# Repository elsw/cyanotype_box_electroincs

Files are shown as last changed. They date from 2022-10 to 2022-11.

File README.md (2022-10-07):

# cyanotype_box_electronics

This is project for use with creating cyanotypes using high power UV LEDs.

These PCBS are designed to control the exposure time and intensity using a LCB screen and keypad

## PCBs

The PCBs are split into 2 parts, control box and light board.

Once control box can support up to 10 light boards daisy chained together

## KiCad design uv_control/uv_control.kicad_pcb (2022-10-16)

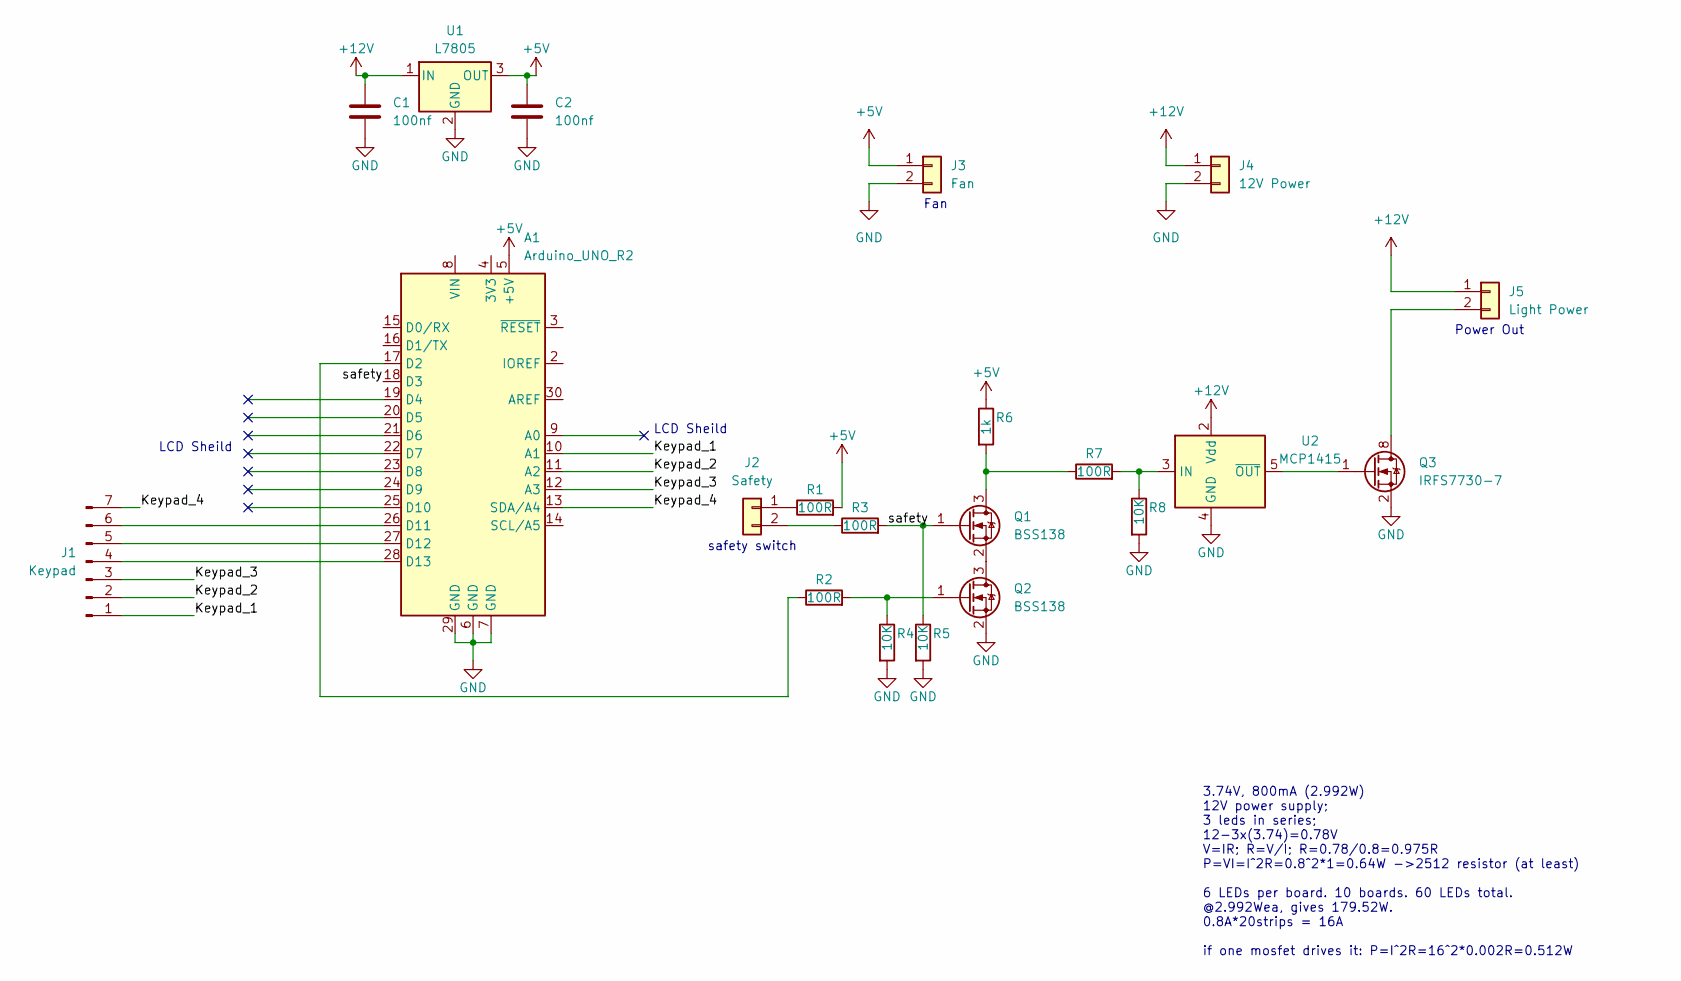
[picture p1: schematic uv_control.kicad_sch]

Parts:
A1: Arduino_UNO_R2
C1, C2: 100nf; C_1206_3216Metric
J1: Keypad; JST_EH_B7B-EH-A_1x07_P2.50mm_Vertical
J2: Safety; JST_EH_B2B-EH-A_1x02_P2.50mm_Vertical
J3: Fan; JST_EH_B2B-EH-A_1x02_P2.50mm_Vertical
J4: 12V Power; AMASS_XT60-M_1x02_P7.20mm_Vertical
J5: Light Power; AMASS_XT60-F_1x02_P7.20mm_Vertical
Q1, Q2: BSS138; SOT-23
Q3: IRFS7730-7; TO-263-7_TabPin8
R1, R2, R3, R7: 100R; R_0805_2012Metric
R4, R5, R8: 10K; R_0805_2012Metric
R6: 1k; R_0805_2012Metric
U1: L7805; TO-252-2
U2: MCP1415; SOT-23-5

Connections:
+5V: A1.5 (+5V), C2.1, J3.1, R1.2, R6.1, U1.3 (OUT)
+12V: C1.1, J4.1, J5.1, U1.1 (IN), U2.2 (Vdd)
/Keypad_1: A1.10 (A1), J1.1
/Keypad_2: A1.11 (A2), J1.2
/Keypad_3: A1.12 (A3), J1.3
/safety: A1.18 (D3), Q1.1 (G), R3.2, R5.1
GND: A1.6 (GND), A1.7 (GND), A1.29 (GND), C1.2, C2.2, J3.2, J4.2, Q2.2 (S), Q3.2 (S), Q3.3 (S), Q3.4 (S), Q3.5 (S), Q3.6 (S), Q3.7 (S), R4.2, R5.2, R8.2, U1.2 (GND), U2.4 (GND)
unnamed: A1.13 (SDA/A4), A1.16 (D1/TX), J1.7
unnamed: A1.17 (D2), R2.1
unnamed: A1.26 (D11), J1.6
unnamed: A1.27 (D12), J1.5
unnamed: A1.28 (D13), J1.4
unnamed: J2.1, R1.1
unnamed: J2.2, R3.1
unnamed: J5.2, Q3.8 (D)
unnamed: Q1.2 (S), Q2.3 (D)
unnamed: Q1.3 (D), R6.2, R7.1
unnamed: Q2.1 (G), R2.2, R4.1
unnamed: Q3.1 (G), U2.5 (~OUT)
unnamed: R7.2, R8.1, U2.3 (IN)

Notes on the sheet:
LCD Sheild
3.74V, 800mA (2.992W) 12V power supply; 3 leds in series; 12-3x(3.74)=0.78V V=IR; R=V/I; R=0.78/0.8=0.975R P=VI=I^2R=0.8^2*1=0.64W ->2512 resistor (at least) 6 LEDs per board. 10 boards. 60 LEDs total. @2.992Wea, gives 179.52W. 0.8A*20strips = 16A if one mosfet drives it: P=I^2R=16^2*0.002R=0.512W
Power Out
Fan
safety switch

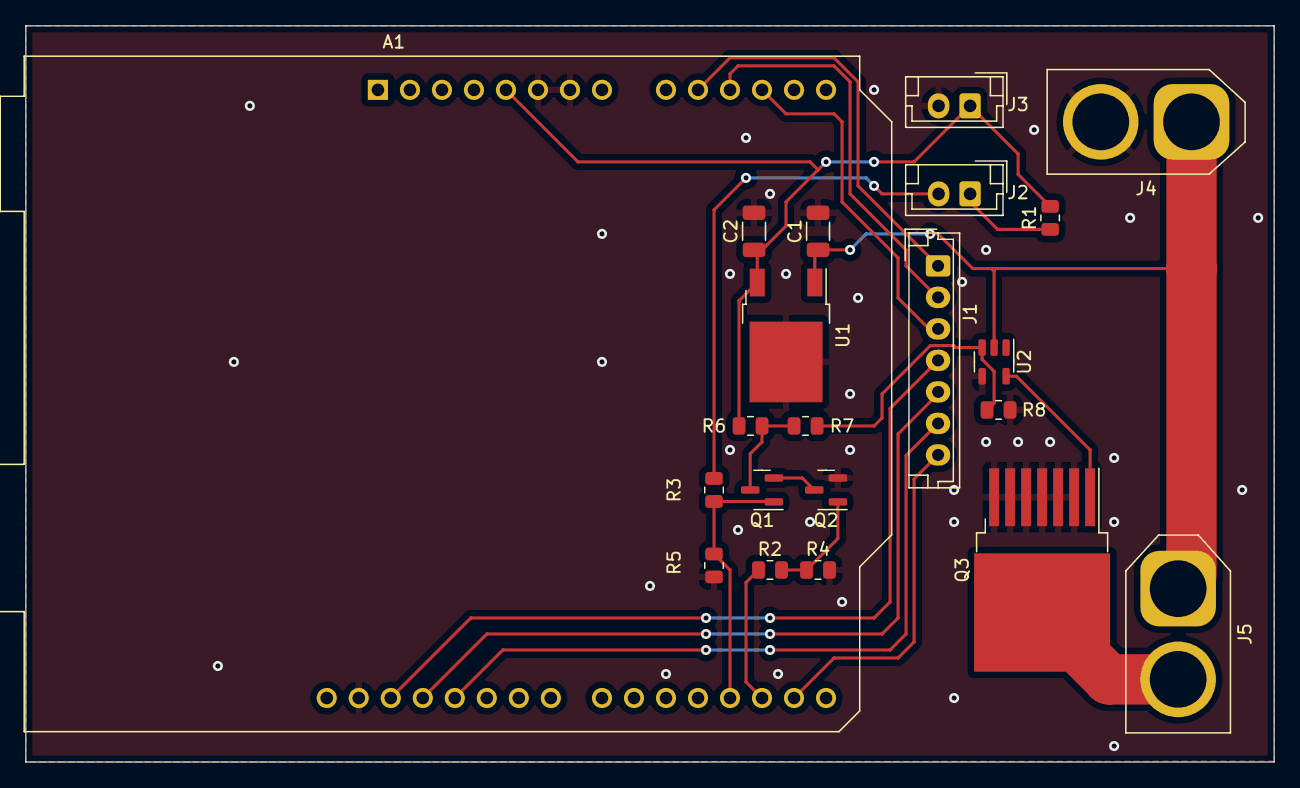
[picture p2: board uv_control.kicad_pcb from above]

Board: 2 copper layers, 99.1 x 58.4 mm, 21 parts (0 on the bottom side), 20 nets.

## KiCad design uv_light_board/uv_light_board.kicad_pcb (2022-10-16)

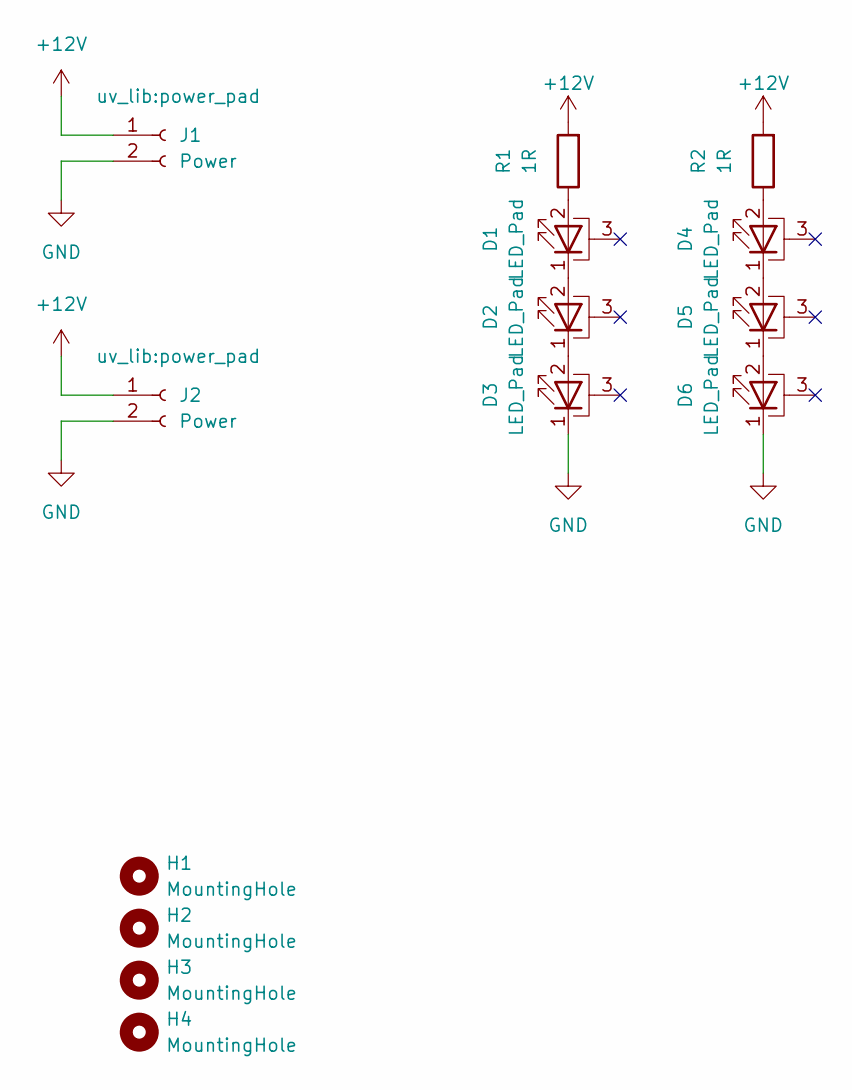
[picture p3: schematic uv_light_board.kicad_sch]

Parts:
D1, D2, D3, D4, D5, D6: LED_Pad; LED_1W_3W_R8
H1, H2, H3, H4: MountingHole; MountingHole_3.2mm_M3
J1, J2: Power; power_pad
R1, R2: 1R; R_2512_6332Metric

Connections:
+12V: J1.1, J2.1, R1.2, R2.2
GND: D3.1 (K), D6.1 (K), J1.2, J2.2
unnamed: D1.1 (K), D2.2 (A)
unnamed: D1.2 (A), R1.1
unnamed: D2.1 (K), D3.2 (A)
unnamed: D4.1 (K), D5.2 (A)
unnamed: D4.2 (A), R2.1
unnamed: D5.1 (K), D6.2 (A)

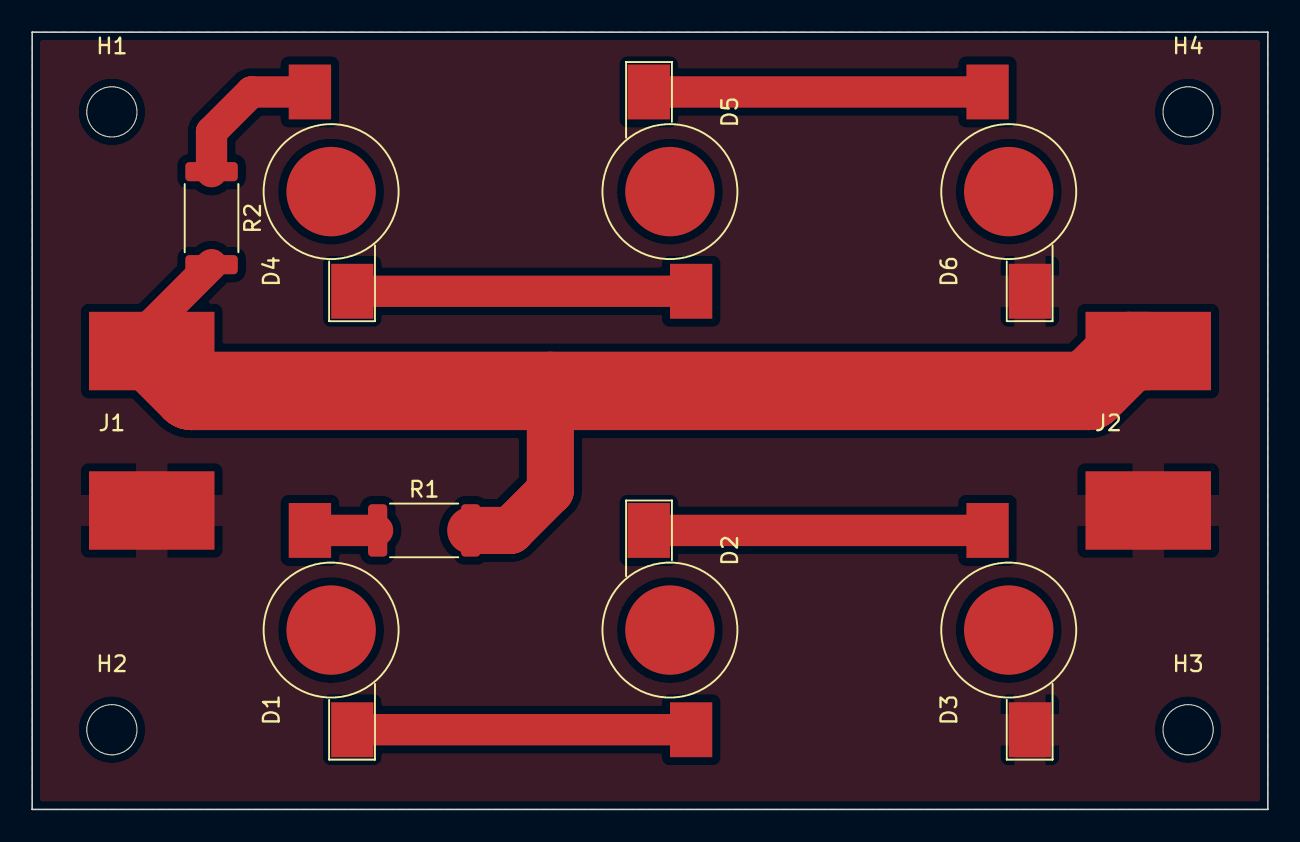
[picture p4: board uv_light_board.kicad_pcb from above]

Board: 2 copper layers, 78.7 x 49.5 mm, 14 parts (0 on the bottom side), 8 nets.

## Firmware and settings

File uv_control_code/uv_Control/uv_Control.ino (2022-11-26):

#include "static.h"
#include <LiquidCrystal.h>
#include <Keypad.h>
#include "state.h"
#include "time_input_state.h"
#include "power_input_state.h"
#include "user_msg_state.h"
#include "powered_state.h"

LiquidCrystal lcd( LCDPins::pin_RS,  LCDPins::pin_EN,  LCDPins::pin_d4,  LCDPins::pin_d5,  LCDPins::pin_d6,  LCDPins::pin_d7);
Keypad keypad = Keypad(makeKeymap(KeypadPins::hexKeys), KeypadPins::rowPins, KeypadPins::colPins, KeypadPins::ROWS, KeypadPins::COLS);
State* states[TOTAL_STATES];
int outputs[TOTAL_STATES];
unsigned current_state;

String user_input;
unsigned timer_s;
unsigned power_percentage;
unsigned last_millis;

void InternalError()
{
  lcd.clear();
  lcd.setCursor(0,0);
  lcd.print("Internal Error");
  lcd.setCursor(0,1);
  lcd.print("State : ");
  lcd.print(current_state);
  delay(1000);
}

void KeyCallback(KeypadEvent key)
{
  //Only trigger on rising edge
  if(keypad.getState() == PRESSED)
  {
    states[current_state]->KeyCallback(key);
  }
}

void setup() 
{
 Serial.begin(9600);
 lcd.begin(16, 2);
 pinMode(PWR_EN_PIN,OUTPUT);
 pinMode(SAFETY_PIN,INPUT);
 //pinMode(STATUS_LED_PIN,OUTPUT);
 pinMode(SAFETY_LED_PIN,OUTPUT);
 keypad.addEventListener(KeyCallback);

 states[STATE_WELCOME] = new UserMsgState(&lcd,"Emilys Amazing","UV Control Box",STATE_WELCOME,STATE_TIMER_INPUT);
 states[STATE_TIMER_INPUT] = new TimeInputState(&lcd);
 states[STATE_POWER_INPUT] = new PowerInputState(&lcd);
 states[STATE_POWERED] = new PoweredState(&lcd,&outputs[0]);
 states[STATE_SAFETY_ERROR] = new UserMsgState(&lcd,"Safety Error!","Continue?",STATE_WELCOME,STATE_POWERED);

 current_state = 0;
 states[current_state]->Setup();
 last_millis = millis();

 //init all outputs to 0
 for(unsigned i = 0 ; i < TOTAL_STATES ; i++)
  outputs[i] = 0;
}

void loop()
{
  unsigned now = millis();
  int delta_millis = now - last_millis;
  last_millis = now;
  //Must call keypad update for the event listener to trigger
  keypad.getKey();

  int safety_ok = digitalRead(SAFETY_PIN);
  digitalWrite(SAFETY_LED_PIN,safety_ok);

  if(current_state < TOTAL_STATES)
  { 
    states[current_state]->Update(delta_millis);

    State::Result result = states[current_state]->GetResult();
    if(result != State::Result::WAITING)
    {
      if(result == State::Result::SUCCESS)
      {
        outputs[current_state] = states[current_state]->GetOutput();
      }
      current_state = states[current_state]->GetNextState();
      if(current_state < TOTAL_STATES)
      {
        states[current_state]->Setup();
      }
      else 
      { 
        InternalError(); 
      }
    }  
  }
  else
  { 
    InternalError(); 
  }
}

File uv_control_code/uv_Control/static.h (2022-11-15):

#pragma once
#include "Arduino.h"

#define TOTAL_STATES 5
enum StateNames
{
  STATE_WELCOME,
  STATE_TIMER_INPUT,
  STATE_POWER_INPUT,
  STATE_POWERED,
  STATE_SAFETY_ERROR
};
#define BACK_KEY '*'
#define CONFIRM_KEY '#'

#define PWR_EN_PIN 2
#define SAFETY_PIN 3
#define STATUS_LED_PIN 10
#define SAFETY_LED_PIN A5

class LCDPins
{
public:
  static const int pin_RS = 8; 
  static const int pin_EN = 9; 
  static const int pin_d4 = 4;
  static const int pin_d5 = 5; 
  static const int pin_d6 = 6; 
  static const int pin_d7 = 7; 
  static const int pin_BL = 10; 
};

class KeypadPins
{
public:
  static const byte ROWS = 4;
  static const byte COLS = 3;
  static const char hexKeys[ROWS][COLS];
  static const byte rowPins[ROWS]; 
  static const byte colPins[COLS]; 

};

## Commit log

2022-10-07 Adding initial PCBs
    [uv_control.kicad_pcb, uv_control.kicad_sch, uv_light_board.kicad_pcb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]
2022-10-16 Updating control board to include more pinouts
    [bom.xlsx, uv_control.kicad_pcb, uv_control.kicad_sch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]
2022-10-31 Adding arduino code
    Added BOM spreadsheet
    [bom.xlsx]
2022-11-05 Updated wiring to avoid Serial debug port
    [uv_control.kicad_sch]
2022-11-11 Updating pinout
    [uv_control.kicad_sch]
2022-11-13 Updating PCB to change to 2 layer setup
    Added LCD schematic, removing LCD shield design
    Fixed XT60 polarity
    Added Status LED and Safety LED
    [uv_control.csv, uv_control.kicad_pcb, uv_control.kicad_sch]
2022-11-15 Updating arduino code
2022-11-15 Reverting to V1 PCB in main branch
    [uv_control.csv, uv_control.kicad_pcb, uv_control.kicad_sch]
2022-11-26 fixing bugs in uv control code
    [uv_Control.ino]
